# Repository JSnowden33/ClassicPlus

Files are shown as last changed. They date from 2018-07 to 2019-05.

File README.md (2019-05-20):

# Classic+
Classic+ is a hardware emulator that replaces the Wii Classic Controller and Nunchuk.  

Classic+
  
### Usage
Classic+ normally operates as a Classic Controller. Nunchuk mode can be enabled at any time by connecting the MD pin to GND. The device can be temporarily disabled by connecting the EN pin to GND. The SDA, SCL, and DET pins should be connected to a Wii Remote expansion port. Unofficial Wii Remotes may not be supported.

The Wii Remote IR camera can be emulated using the right joystick only in Nunchuk mode. This feature is only supported on non-TR Wii Remotes. The real IR camera must be removed from the Wii Remote before using IR camera emulation. Sensitivity adjustment is available in the homebrew app.

Soldering the accelerometer IC is optional. Without it, Nunchuk mode will report neutral values.

Classic+ works with Wii Remotes and SNES Classic. NES Classic support is untested.

PCBs can be ordered here: https://oshpark.com/shared_projects/poSQyyw2
  
### Updating
Place `update.hex` from the Firmware folder on the root of an SD card or USB storage device. Run the Wii homebrew app with a Classic+ board connected to a Wii Remote and select "Update Classic+". Note that the update process can take up to 10 minutes.

### Safe Mode
Safe mode can be enabled by holding the X and Y buttons when the Classic+ powers on. Safe mode only supports updating through the homebrew app. Buttons, joysticks, and calibration will not work.
  
### Programming
Flash the pre-compiled `firmware.hex` using MPLAB IPE with a PICkit 3.

### Compiling
Make a project in MPLAB X IDE for PIC16F18876 with the XC8 compiler. The Bootloader and Main Program must be compiled as separate projects and flashed onto the same device using the code offset and Preserve Program Memory features or by manually combining the compiled .hex files.

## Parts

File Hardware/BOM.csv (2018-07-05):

Part | Value | Package
U1 | PIC16F18876-I/MV | UQFN-40
U2 | LSM6DS3USTR | LGA-14
C1 | 0.1 µF | 0603
C2 | 0.1 µF | 0603
C3 | 0.1 µF | 0603
C4 | 0.1 µF | 0603
R1 | 4.7 kΩ | 0603
R2 | 4.7 kΩ | 0603
R3 | 4.7 kΩ | 0603
R4 | 4.7 kΩ | 0603

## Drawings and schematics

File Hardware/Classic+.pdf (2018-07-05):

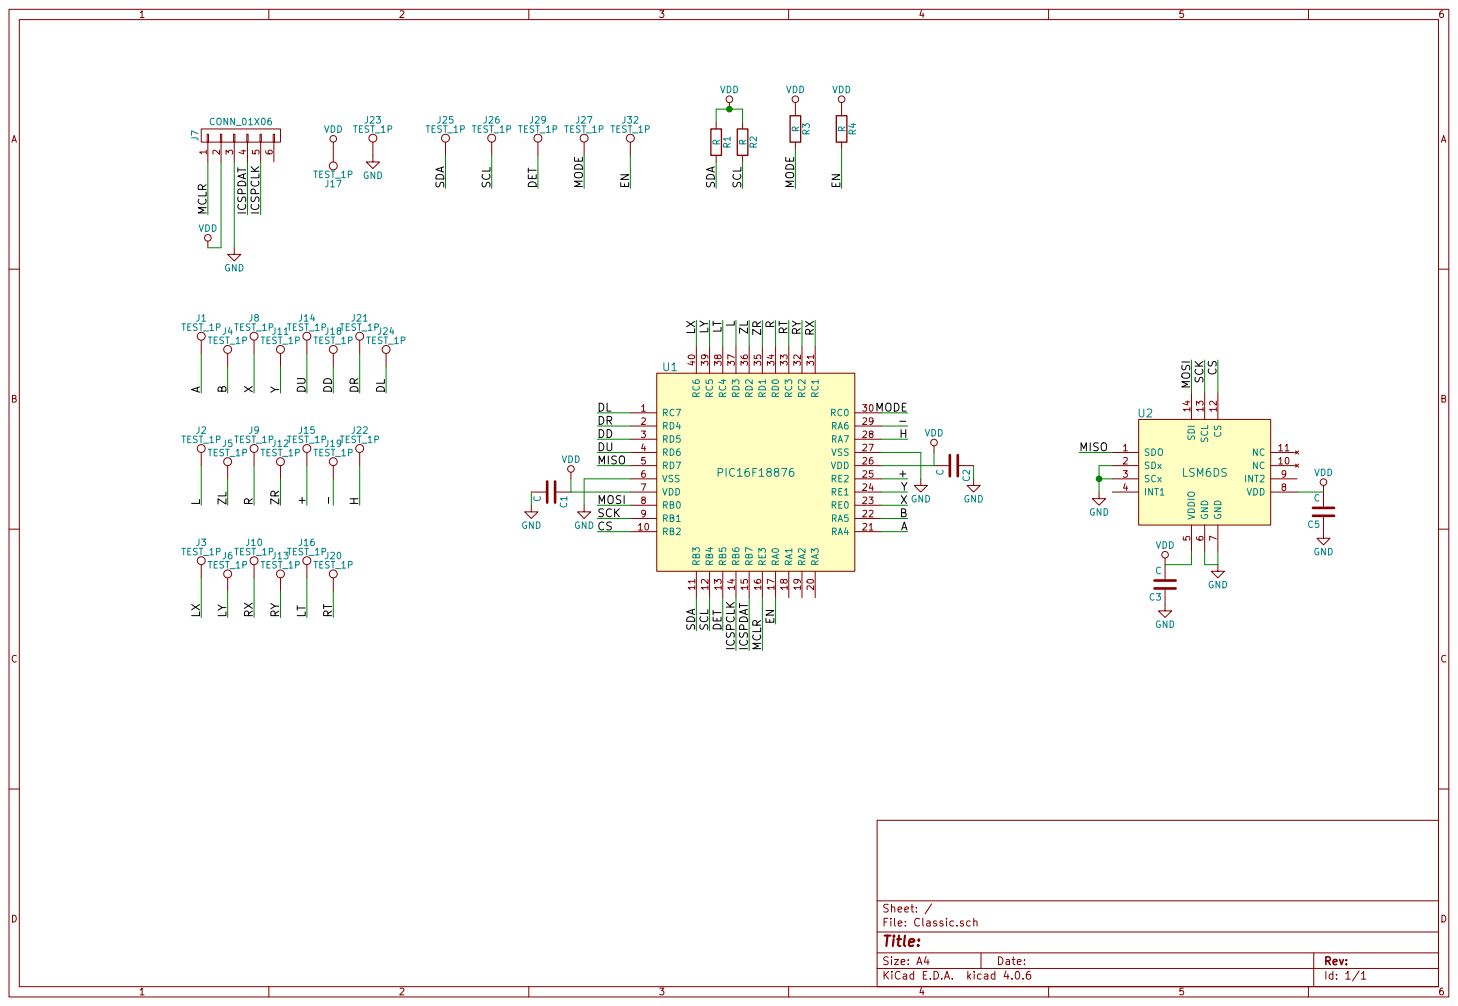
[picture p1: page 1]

RR1RR2 VDD SDA SCL SDA SCL

Id: 1/1 Title: File: Classic.sch Sheet: /

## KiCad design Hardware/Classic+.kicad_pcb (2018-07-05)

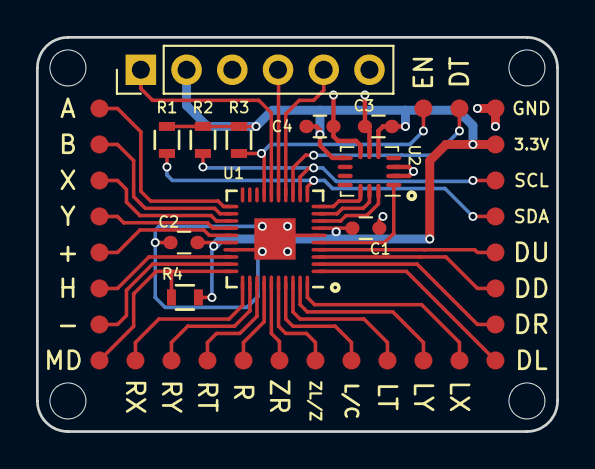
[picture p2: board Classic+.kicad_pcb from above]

Board: 2 copper layers, 28.9 x 21.9 mm, 39 parts (0 on the bottom side), 35 nets.

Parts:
C1, C2, C3, C5: C; C_0603
J1, J2, J3, J4, J5, J6, J8, J9, J10, J11, J12, J13, J14, J15, J16, J17, J18, J19, J20, J21, J22, J23, J24, J25, J26, J27, J29, J32: TEST_1P; Test_Pad
J7: CONN_01X06; Pin_Header_Straight_1x06_Pitch2.54mm
R1, R2, R3, R4: R; R_0603
U1: PIC16F18875; QFN-40-1EP_5x5mm_Pitch0.4mm
U2: LSM6DS; LGA-14_3x2.5mm_Pitch0.5mm

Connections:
/+: J15.1, U1.25
/-: J19.1, U1.29
/A: J1.1, U1.21
/B: J4.1, U1.22
/CS: U1.10, U2.12
/DD: J18.1, U1.3
/DET: J29.1, U1.13
/DL: J24.1, U1.1
/DR: J21.1, U1.2
/DU: J14.1, U1.4
/EN: J32.1, R4.2, U1.17
/H: J22.1, U1.28
/ICSPCLK: J7.5, U1.14
/ICSPDAT: J7.4, U1.15
/L: J2.1, U1.37
/LT: J16.1, U1.38
/LX: J3.1, U1.40
/LY: J6.1, U1.39
/MCLR: J7.1, U1.16
/MISO: U1.5, U2.1
/MODE: J27.1, R3.2, U1.30
/MOSI: U1.8, U2.14
/R: J9.1, U1.34
/RT: J20.1, U1.33
/RX: J10.1, U1.31
/RY: J13.1, U1.32
/SCK: U1.9, U2.13
/SCL: J26.1, R2.2, U1.12
/SDA: J25.1, R1.2, U1.11
/X: J8.1, U1.23
/Y: J11.1, U1.24
/ZL: J5.1, U1.36
/ZR: J12.1, U1.35
GND: C1.2, C2.1, C3.1, C5.1, J7.3, J23.1, U1.6, U1.27, U1.41, U2.2, U2.3, U2.6, U2.7
VDD: C1.1, C2.2, C3.2, C5.2, J7.2, J17.1, R1.1, R2.1, R3.1, R4.1, U1.7, U1.26, U2.5, U2.8

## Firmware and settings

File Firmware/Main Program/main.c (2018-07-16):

/*
 * File:   main.c
 * Author: Jackson Snowden
 */

// PIC16F18876 Configuration Bit Settings

// 'C' source line config statements

// CONFIG1
#pragma config FEXTOSC = OFF    // External Oscillator mode selection bits (Oscillator not enabled)
#pragma config RSTOSC = HFINT32 // Power-up default value for COSC bits (HFINTOSC with OSCFRQ = 32 MHz and CDIV = 1:1)
#pragma config CLKOUTEN = OFF   // Clock Out Enable bit (CLKOUT function is disabled; i/o or oscillator function on OSC2)
#pragma config CSWEN = ON       // Clock Switch Enable bit (Writing to NOSC and NDIV is allowed)
#pragma config FCMEN = ON       // Fail-Safe Clock Monitor Enable bit (FSCM timer enabled)

// CONFIG2
#pragma config MCLRE = ON       // Master Clear Enable bit (MCLR pin is Master Clear function)
#pragma config PWRTE = OFF      // Power-up Timer Enable bit (PWRT disabled)
#pragma config LPBOREN = OFF    // Low-Power BOR enable bit (ULPBOR disabled)
#pragma config BOREN = ON       // Brown-out reset enable bits (Brown-out Reset Enabled, SBOREN bit is ignored)
#pragma config BORV = LO        // Brown-out Reset Voltage Selection (Brown-out Reset Voltage (VBOR) set to 1.9V on LF, and 2.45V on F Devices)
#pragma config ZCD = OFF        // Zero-cross detect disable (Zero-cross detect circuit is disabled at POR.)
#pragma config PPS1WAY = OFF    // Peripheral Pin Select one-way control (The PPSLOCK bit can be set and cleared repeatedly by software)
#pragma config STVREN = ON      // Stack Overflow/Underflow Reset Enable bit (Stack Overflow or Underflow will cause a reset)

// CONFIG3
#pragma config WDTCPS = WDTCPS_31// WDT Period Select bits (Divider ratio 1:65536; software control of WDTPS)
#pragma config WDTE = OFF       // WDT operating mode (WDT Disabled, SWDTEN is ignored)
#pragma config WDTCWS = WDTCWS_7// WDT Window Select bits (window always open (100%); software control; keyed access not required)
#pragma config WDTCCS = LFINTOSC// WDT input clock selector (WDT reference clock is the 31.0kHz LFINTOSC output)

// CONFIG4
#pragma config WRT = OFF        // UserNVM self-write protection bits (Write protection off)
#pragma config SCANE = not_available// Scanner Enable bit (Scanner module is not available for use)
#pragma config LVP = ON         // Low Voltage Programming Enable bit (Low Voltage programming enabled. MCLR/Vpp pin function is MCLR.)

// CONFIG5
#pragma config CP = OFF         // UserNVM Program memory code protection bit (Program Memory code protection disabled)
#pragma config CPD = OFF        // DataNVM code protection bit (Data EEPROM code protection disabled)

#include <xc.h>
#include "config.h"
#include "pin_defs.h"
#include "input.h"
#include "ADC.h"
#include "MSSP.h"
#include "expansion.h"
#include "camera.h"

u8 mode;
u8 newMode;

void PPSunlock()
{
    PPSLOCK = 0x55;
    PPSLOCK = 0xAA;
    PPSLOCKbits.PPSLOCKED = 0;
}

void PPSlock()
{
    PPSLOCK = 0x55;
    PPSLOCK = 0xAA;
    PPSLOCKbits.PPSLOCKED = 1;
}

void PICinit()
{
    // INTOSC = 8 MHz
    OSCCON1bits.NDIV = 2;
    
    INTCONbits.GIE = 0;
    PPSunlock();
    
    // I2C pin mapping
    SSP1DATPPS = PPS_RB3;   // SDA input on RB3
    RB3PPS = PPS_SDA1;      // SDA output on RB3
    SSP1CLKPPS = PPS_RB4;   // SCL input on RB4
    RB4PPS = PPS_SCL1;      // SCL output on RB4
    
    // SPI pin mapping
    RB0PPS = PPS_SDO2;      // SDO on RB0
    SSP2DATPPS = PPS_RD7;   // SDI on RD7
    RB1PPS = PPS_SCK2;      // SCK output on RB1
    
    PPSlock();
    
    // Enable MSSP1 interrupt
    SSP1IF = 0;
    PIE3 = 0b00000001;
    INTCON = 0b11000000;  
    
    // Pull-ups on button inputs
    WPUA = 0b11110000;    
    WPUB = 0b00000000;
    WPUC = 0b10000000;  
    WPUD = 0b01111111;  
    WPUE = 0b00000111;  
    
    // Analog pins: RC1, RC2, RC3, RC4, RC5, RC6
    ANSELA = 0b00000000;
    ANSELB = 0b00000000;
    ANSELC = 0b01111110;
    ANSELD = 0b00000000;
    ANSELE = 0b00000000;
    
    // Output pins: RB0, RB1, RB2, RB5
    TRISA = 0b11111111;   
    TRISB = 0b11011000;
    TRISC = 0b11111111;
    TRISD = 0b11111111;
    TRISE = 0b11111111;
    
    // Initial output pin states
    DETECT = 0;
    CS = 1;
}

void BeginBootloader()
{
    // Go to bootloader address
    #asm
        GOTO BOOT_ADDR;
    #endasm
}

void interrupt ISR()
{   
    if (SSP1IF)
    {       
        I2CslaveHandle();
        I2CslaveRelease();
        
        SSP1IF = 0;
    }
}

void main()
{
    PICinit();
    InputInit();
    
    mode = 0xFF;
    newMode = 0;
    
    while(1)
    {
        // Poll mode/enable pins
        if (ENABLE)
        {
            if (MODE) newMode = MODE_CLASSIC;
            else newMode = MODE_NUNCHUK;
        }
        else newMode = MODE_OFF;
        
        // Update mode
        if (newMode != mode) 
        {
            ExpSetMode(newMode);
            mode = newMode;
        }
        
        if (ExpIsEnabled())
        {
            InputGetButtons(mode);  // Get current button states
            InputGetAxes(mode);     // Get current axis states
            ExpUpdate();            // Send controller data to Wii Remote
            CamUpdateBlobs();       // Send camera data to Wii Remote
            
            // Execute special commands, go to bootloader if triggered
            if (ExpCmdExec()) BeginBootloader();
        }
    }
}

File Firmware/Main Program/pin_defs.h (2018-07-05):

/* 
 * File:   pin_defs.h  
 * Author: Jackson Snowden
 */

#ifndef _PIN_DEFS_H_
#define	_PIN_DEFS_H_

// Button pin definitions
#define A_PIN       RA4
#define B_PIN       RA5
#define X_PIN       RE0
#define Y_PIN       RE1
#define DU_PIN      RD6
#define DD_PIN      RD5
#define DR_PIN      RD4
#define DL_PIN      RC7
#define R_PIN       RD0
#define ZR_PIN      RD1
#define L_PIN       RD3
#define ZL_PIN      RD2
#define PLUS_PIN    RE2
#define MINUS_PIN   RA6
#define HOME_PIN    RA7
#define C_PIN       L_PIN
#define Z_PIN       ZL_PIN

// Axis pin definitions
#define LX_PIN  RC6
#define LY_PIN  RC5
#define RX_PIN  RC1
#define RY_PIN  RC2
#define LT_PIN  RC4
#define RT_PIN  RC3

// Axis ADC channel definitions
#define LX_CH   22
#define LY_CH   21
#define RX_CH   17
#define RY_CH   18
#define LT_CH   20
#define RT_CH   19

// Communication pin definitions
#define MOSI    LATB0
#define MISO    RD7
#define SCK     LATB1
#define CS      LATB2
#define SDA     RB3
#define SCL     RB4
#define DETECT  LATB5
#define MODE    RC0
#define ENABLE  RA0

// PPS output signal names
#define PPS_SDA2    0x17
#define PPS_SDO2    0x17
#define PPS_SCL2    0x16
#define PPS_SCK2    0x16
#define PPS_SDA1    0x15
#define PPS_SDO1    0x15
#define PPS_SCL1    0x14
#define PPS_SCK1    0x14

// PPS input pin names
#define PPS_RB0     0x08
#define PPS_RB1     0x09
#define PPS_RB2     0x0A
#define PPS_RB3     0x0B
#define PPS_RB4     0x0C
#define PPS_RD7     0x1F

#endif  /* _PIN_DEFS_H_ */

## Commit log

2018-07-16 Add IR camera compatibility
2019-05-20 Attach image
